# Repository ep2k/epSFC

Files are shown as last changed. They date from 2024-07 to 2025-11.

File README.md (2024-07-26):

# epSFC - SUPER Famicom Emulator on an FPGA

epSFC is an implementation of Nintendo's __SUPER Famicom (SFC)__ written in SystemVerilog.
It works on an FPGA board with a board for connection to SFC cartridges.

The operation has been confirmed with Terasic DE0-CV Board.

<br>

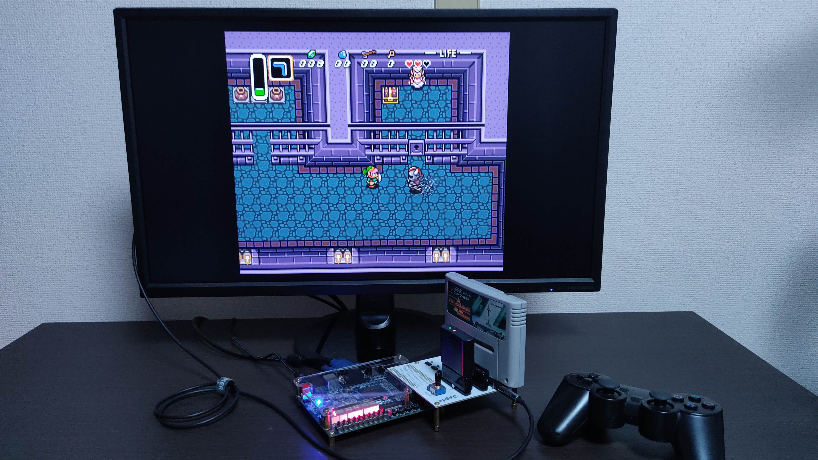
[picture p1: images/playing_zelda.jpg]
Playing The Legend of Zelda: A Link to the Past Playing The Legend of Zelda: A Link to the Past (1991, Nintendo)


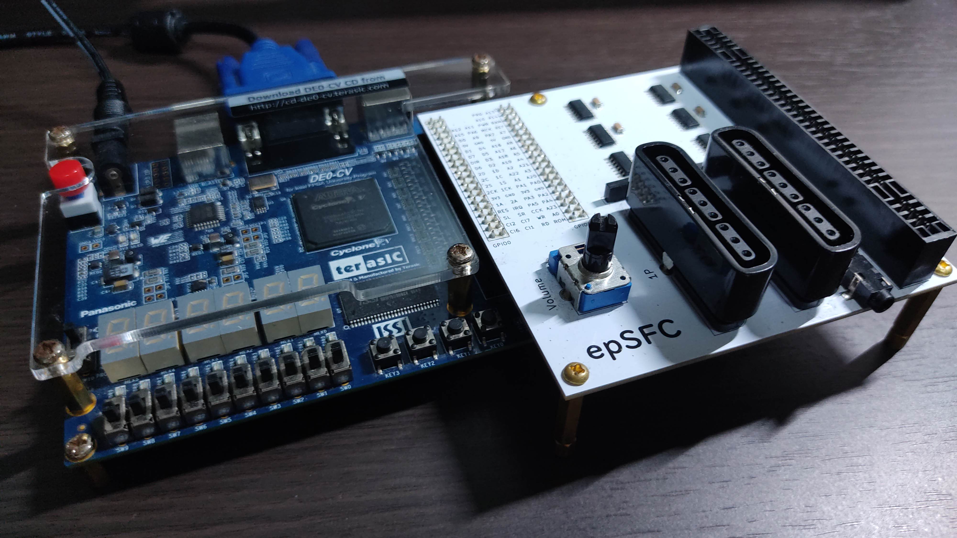
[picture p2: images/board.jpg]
Terasic DE0-CV and my own board for connecting the FPGA and SFC cartridges


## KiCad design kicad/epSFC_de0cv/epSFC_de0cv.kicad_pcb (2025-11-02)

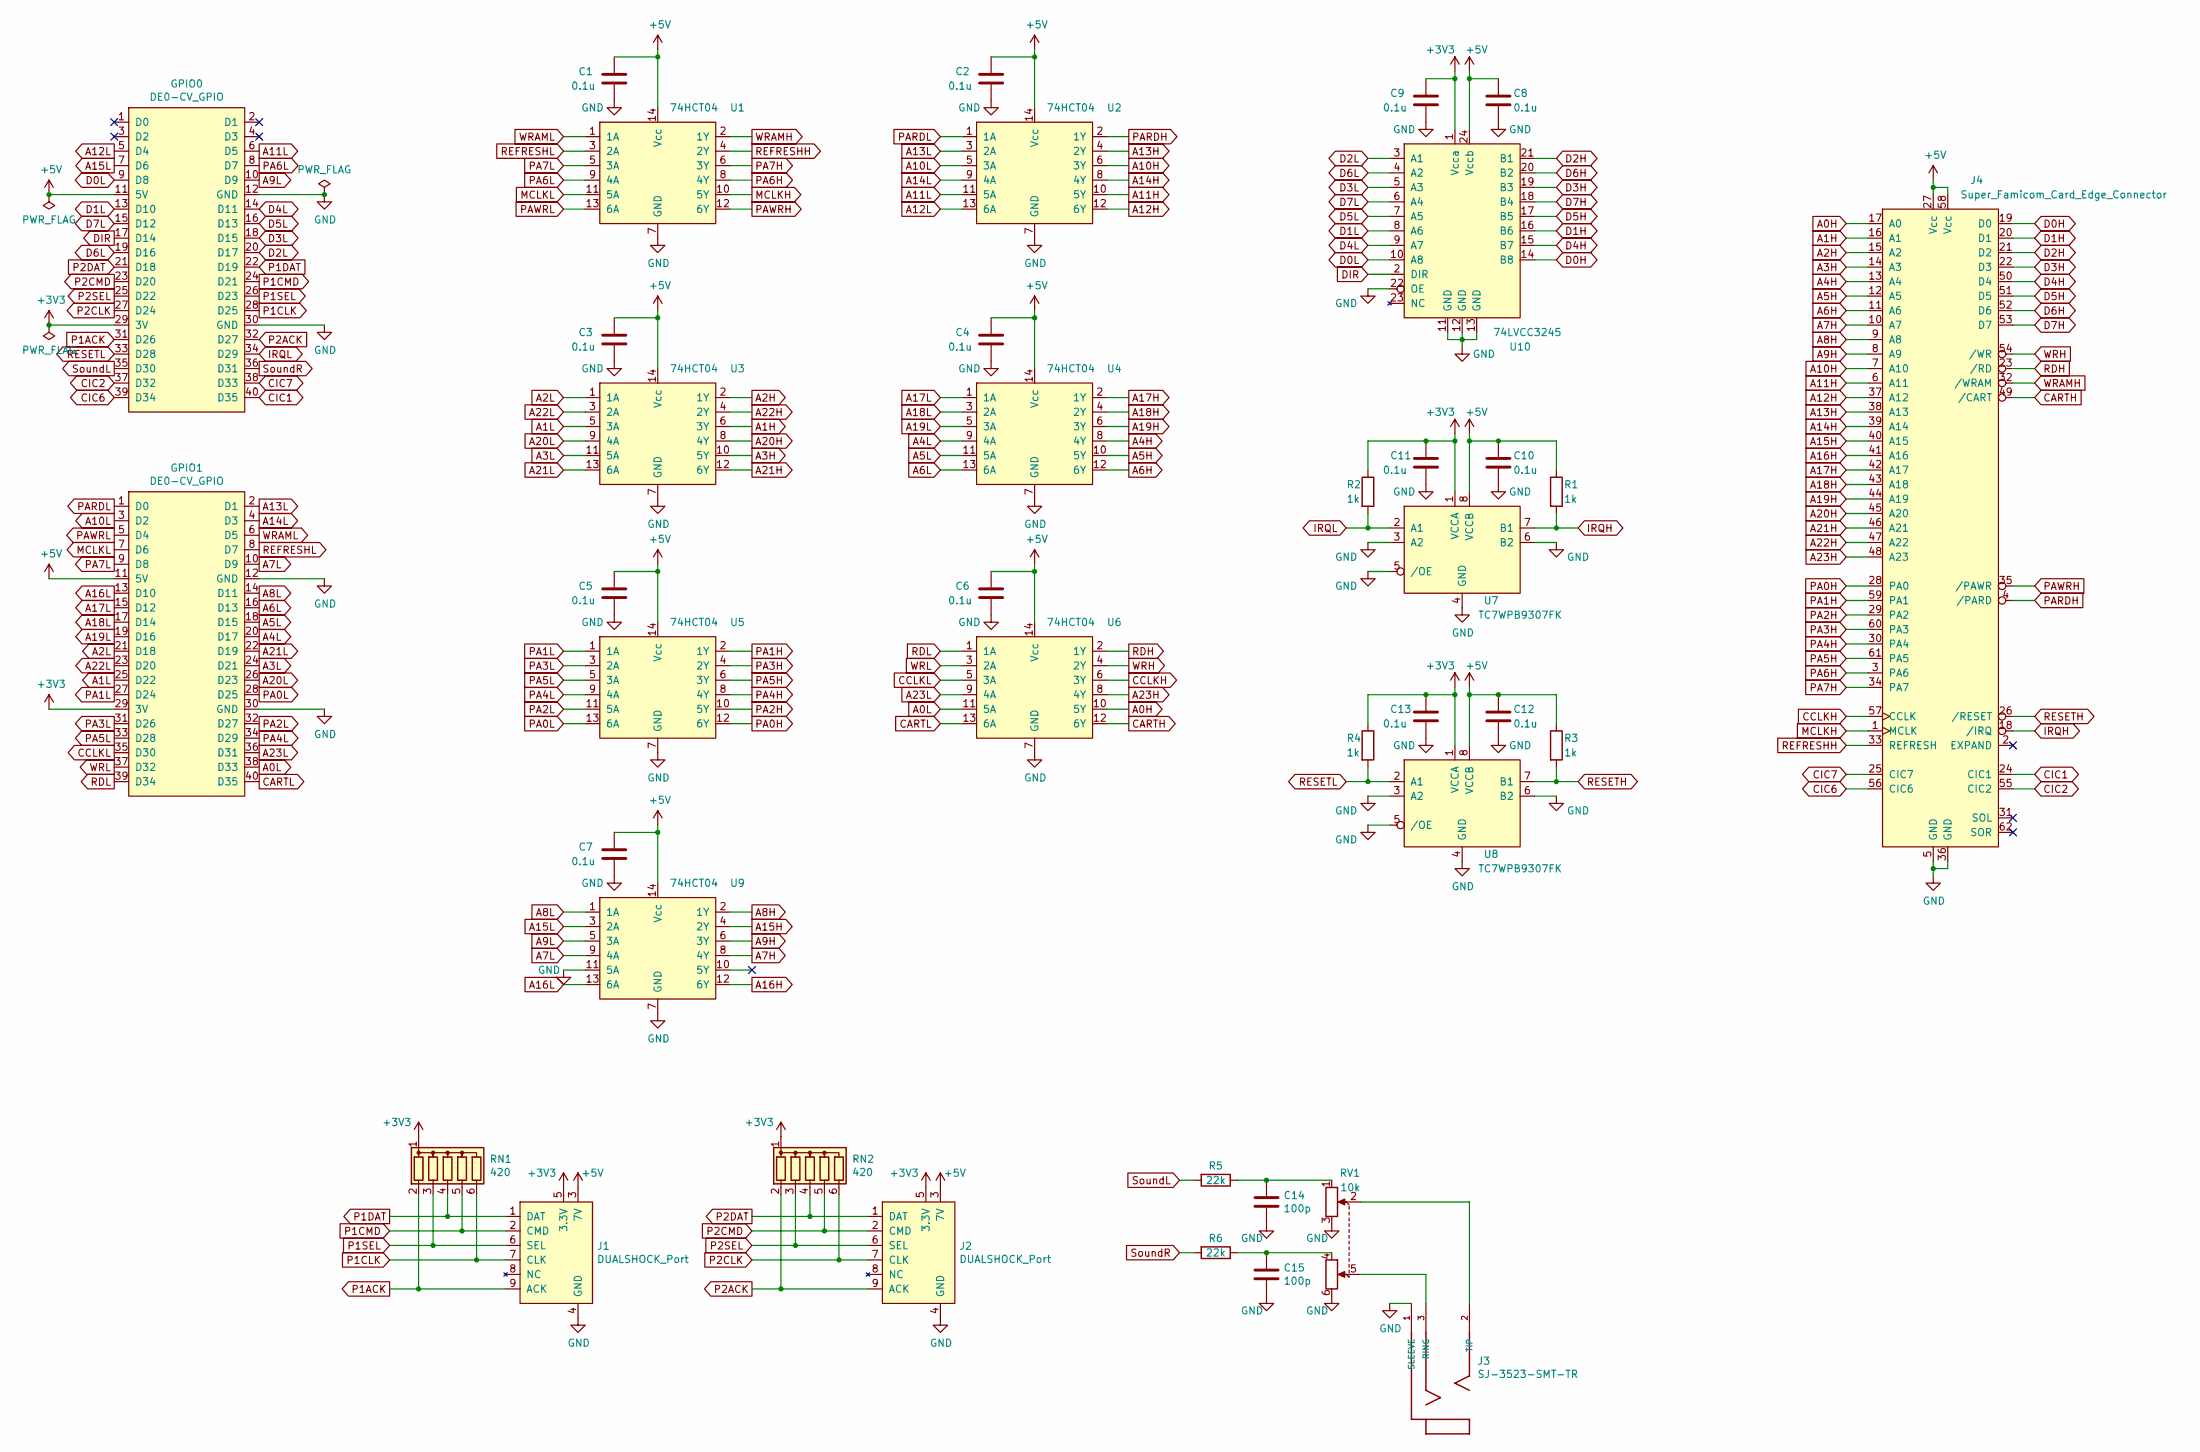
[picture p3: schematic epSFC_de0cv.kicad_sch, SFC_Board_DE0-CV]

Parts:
C1, C2, C3, C4, C5, C6, C7, C8, C9, C10, C11, C12, C13: 0.1u; C_1206_3216Metric_Pad1.33x1.80mm_HandSolder
C14, C15: 100p; C_1206_3216Metric_Pad1.33x1.80mm_HandSolder
GPIO0, GPIO1: DE0-CV_GPIO; PinSocket_2x20_P2.54mm_Vertical_Back
J1, J2: DUALSHOCK_Port
J3: SJ-3523-SMT-TR; CUI_SJ-3523-SMT-TR
J4: Super_Famicom_Card_Edge_Connector; SuperFamicom_Card_Edge_Connector
R1, R2, R3, R4: 1k; R_1206_3216Metric_Pad1.30x1.75mm_HandSolder
R5, R6: 22k; R_1206_3216Metric_Pad1.30x1.75mm_HandSolder
RN1, RN2: 420; R_Array_SIP6
RV1: 10k; Potentiometer_Bourns_PTV112
U1, U2, U3, U4, U5, U6, U9: 74HCT04; SOIC-14_3.9x8.7mm_P1.27mm
U7, U8: TC7WPB9307FK; US8
U10: 74LVCC3245; SO-24_5.3x15mm_P1.27mm

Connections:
+3V3: C9.1, C11.1, C13.1, GPIO0.29 (3V), GPIO1.29 (3V), J1.5 (3.3V), J2.5 (3.3V), R2.1, R4.1, RN1.1 (common), RN2.1 (common), U7.1 (VCCA), U8.1 (VCCA), U10.1 (Vcca)
+5V: C1.1, C2.1, C3.1, C4.1, C5.1, C6.1, C7.1, C8.1, C10.1, C12.1, GPIO0.11 (5V), GPIO1.11 (5V), J1.3 (7V), J2.3 (7V), J4.27 (Vcc), J4.58 (Vcc), R1.1, R3.1, U1.14 (Vcc), U2.14 (Vcc), U3.14 (Vcc), U4.14 (Vcc), U5.14 (Vcc), U6.14 (Vcc), U7.8 (VCCB), U8.8 (VCCB), U9.14 (Vcc), U10.24 (Vccb)
A0H: J4.17 (A0), U6.10 (5Y)
A0L: GPIO1.38 (D33), U6.11 (5A)
A1H: J4.16 (A1), U3.6 (3Y)
A1L: GPIO1.25 (D22), U3.5 (3A)
A2H: J4.15 (A2), U3.2 (1Y)
A2L: GPIO1.21 (D18), U3.1 (1A)
A3H: J4.14 (A3), U3.10 (5Y)
A3L: GPIO1.24 (D21), U3.11 (5A)
A4H: J4.13 (A4), U4.8 (4Y)
A4L: GPIO1.20 (D17), U4.9 (4A)
A5H: J4.12 (A5), U4.10 (5Y)
A5L: GPIO1.18 (D15), U4.11 (5A)
A6H: J4.11 (A6), U4.12 (6Y)
A6L: GPIO1.16 (D13), U4.13 (6A)
A7H: J4.10 (A7), U9.8 (4Y)
A7L: GPIO1.10 (D9), U9.9 (4A)
A8H: J4.9 (A8), U9.2 (1Y)
A8L: GPIO1.14 (D11), U9.1 (1A)
A9H: J4.8 (A9), U9.6 (3Y)
A9L: GPIO0.10 (D9), U9.5 (3A)
A10H: J4.7 (A10), U2.6 (3Y)
A10L: GPIO1.3 (D2), U2.5 (3A)
A11H: J4.6 (A11), U2.10 (5Y)
A11L: GPIO0.6 (D5), U2.11 (5A)
A12H: J4.37 (A12), U2.12 (6Y)
A12L: GPIO0.5 (D4), U2.13 (6A)
A13H: J4.38 (A13), U2.4 (2Y)
A13L: GPIO1.2 (D1), U2.3 (2A)
A14H: J4.39 (A14), U2.8 (4Y)
A14L: GPIO1.4 (D3), U2.9 (4A)
A15H: J4.40 (A15), U9.4 (2Y)
A15L: GPIO0.7 (D6), U9.3 (2A)
A16H: J4.41 (A16), U9.12 (6Y)
A16L: GPIO1.13 (D10), U9.13 (6A)
A17H: J4.42 (A17), U4.2 (1Y)
A17L: GPIO1.15 (D12), U4.1 (1A)
A18H: J4.43 (A18), U4.4 (2Y)
A18L: GPIO1.17 (D14), U4.3 (2A)
A19H: J4.44 (A19), U4.6 (3Y)
A19L: GPIO1.19 (D16), U4.5 (3A)
A20H: J4.45 (A20), U3.8 (4Y)
A20L: GPIO1.26 (D23), U3.9 (4A)
A21H: J4.46 (A21), U3.12 (6Y)
A21L: GPIO1.22 (D19), U3.13 (6A)
A22H: J4.47 (A22), U3.4 (2Y)
A22L: GPIO1.23 (D20), U3.3 (2A)
A23H: J4.48 (A23), U6.8 (4Y)
A23L: GPIO1.36 (D31), U6.9 (4A)
CARTH: J4.49 (/CART), U6.12 (6Y)
CARTL: GPIO1.40 (D35), U6.13 (6A)
CCLKH: J4.57 (CCLK), U6.6 (3Y)
CCLKL: GPIO1.35 (D30), U6.5 (3A)
CIC1: GPIO0.40 (D35), J4.24 (CIC1)
CIC2: GPIO0.37 (D32), J4.55 (CIC2)
CIC6: GPIO0.39 (D34), J4.56 (CIC6)
CIC7: GPIO0.38 (D33), J4.25 (CIC7)
D0H: J4.19 (D0), U10.14 (B8)
D0L: GPIO0.9 (D8), U10.10 (A8)
D1H: J4.20 (D1), U10.16 (B6)
D1L: GPIO0.13 (D10), U10.8 (A6)
D2H: J4.21 (D2), U10.21 (B1)
D2L: GPIO0.20 (D17), U10.3 (A1)
D3H: J4.22 (D3), U10.19 (B3)
D3L: GPIO0.18 (D15), U10.5 (A3)
D4H: J4.50 (D4), U10.15 (B7)
D4L: GPIO0.14 (D11), U10.9 (A7)
D5H: J4.51 (D5), U10.17 (B5)
D5L: GPIO0.16 (D13), U10.7 (A5)
D6H: J4.52 (D6), U10.20 (B2)
D6L: GPIO0.19 (D16), U10.4 (A2)
D7H: J4.53 (D7), U10.18 (B4)
D7L: GPIO0.15 (D12), U10.6 (A4)
DIR: GPIO0.17 (D14), U10.2 (DIR)
GND: C1.2, C2.2, C3.2, C4.2, C5.2, C6.2, C7.2, C8.2, C9.2, C10.2, C11.2, C12.2, C13.2, C14.2, C15.2, GPIO0.12 (GND), GPIO0.30 (GND), GPIO1.12 (GND), GPIO1.30 (GND), J1.4 (GND), J2.4 (GND), J3.1 (SLEEVE), J4.5 (GND), J4.36 (GND), RV1.3, RV1.6, U1.7 (GND), U2.7 (GND), U3.7 (GND), U4.7 (GND), U5.7 (GND), U6.7 (GND), U7.3 (A2), U7.4 (GND), U7.5 (/OE), U7.6 (B2), U8.3 (A2), U8.4 (GND), U8.5 (/OE), U8.6 (B2), U9.7 (GND), U9.11 (5A), U10.11 (GND), U10.12 (GND), U10.13 (GND), U10.22 (OE)
IRQH: J4.18 (/IRQ), R1.2, U7.7 (B1)
IRQL: GPIO0.34 (D29), R2.2, U7.2 (A1)
MCLKH: J4.1 (MCLK), U1.10 (5Y)
MCLKL: GPIO1.7 (D6), U1.11 (5A)
unnamed: C14.1, R5.1, RV1.1
unnamed: C15.1, R6.1, RV1.4
unnamed: J3.3 (RING), RV1.5
unnamed: J3.2 (TIP), RV1.2
P1ACK: GPIO0.31 (D26), J1.9 (ACK), RN1.2 (R1)
P1CLK: GPIO0.28 (D25), J1.7 (CLK), RN1.6 (R5)
P1CMD: GPIO0.24 (D21), J1.2 (CMD), RN1.5 (R4)
P1DAT: GPIO0.22 (D19), J1.1 (DAT), RN1.4 (R3)
P1SEL: GPIO0.26 (D23), J1.6 (SEL), RN1.3 (R2)
P2ACK: GPIO0.32 (D27), J2.9 (ACK), RN2.2 (R1)
P2CLK: GPIO0.27 (D24), J2.7 (CLK), RN2.6 (R5)
P2CMD: GPIO0.23 (D20), J2.2 (CMD), RN2.5 (R4)
P2DAT: GPIO0.21 (D18), J2.1 (DAT), RN2.4 (R3)
P2SEL: GPIO0.25 (D22), J2.6 (SEL), RN2.3 (R2)
PA0H: J4.28 (PA0), U5.12 (6Y)
PA0L: GPIO1.28 (D25), U5.13 (6A)
PA1H: J4.59 (PA1), U5.2 (1Y)
PA1L: GPIO1.27 (D24), U5.1 (1A)
PA2H: J4.29 (PA2), U5.10 (5Y)
PA2L: GPIO1.32 (D27), U5.11 (5A)
PA3H: J4.60 (PA3), U5.4 (2Y)
PA3L: GPIO1.31 (D26), U5.3 (2A)
PA4H: J4.30 (PA4), U5.8 (4Y)
PA4L: GPIO1.34 (D29), U5.9 (4A)
PA5H: J4.61 (PA5), U5.6 (3Y)
PA5L: GPIO1.33 (D28), U5.5 (3A)
PA6H: J4.3 (PA6), U1.8 (4Y)
PA6L: GPIO0.8 (D7), U1.9 (4A)
PA7H: J4.34 (PA7), U1.6 (3Y)
PA7L: GPIO1.9 (D8), U1.5 (3A)
PARDH: J4.4 (/PARD), U2.2 (1Y)
PARDL: GPIO1.1 (D0), U2.1 (1A)
PAWRH: J4.35 (/PAWR), U1.12 (6Y)
PAWRL: GPIO1.5 (D4), U1.13 (6A)
RDH: J4.23 (/RD), U6.2 (1Y)
RDL: GPIO1.39 (D34), U6.1 (1A)
REFRESHH: J4.33 (REFRESH), U1.4 (2Y)
REFRESHL: GPIO1.8 (D7), U1.3 (2A)
RESETH: J4.26 (/RESET), R3.2, U8.7 (B1)
RESETL: GPIO0.33 (D28), R4.2, U8.2 (A1)
SoundL: GPIO0.35 (D30), R5.2
SoundR: GPIO0.36 (D31), R6.2
WRAMH: J4.32 (/WRAM), U1.2 (1Y)
WRAML: GPIO1.6 (D5), U1.1 (1A)
WRH: J4.54 (/WR), U6.4 (2Y)
WRL: GPIO1.37 (D32), U6.3 (2A)

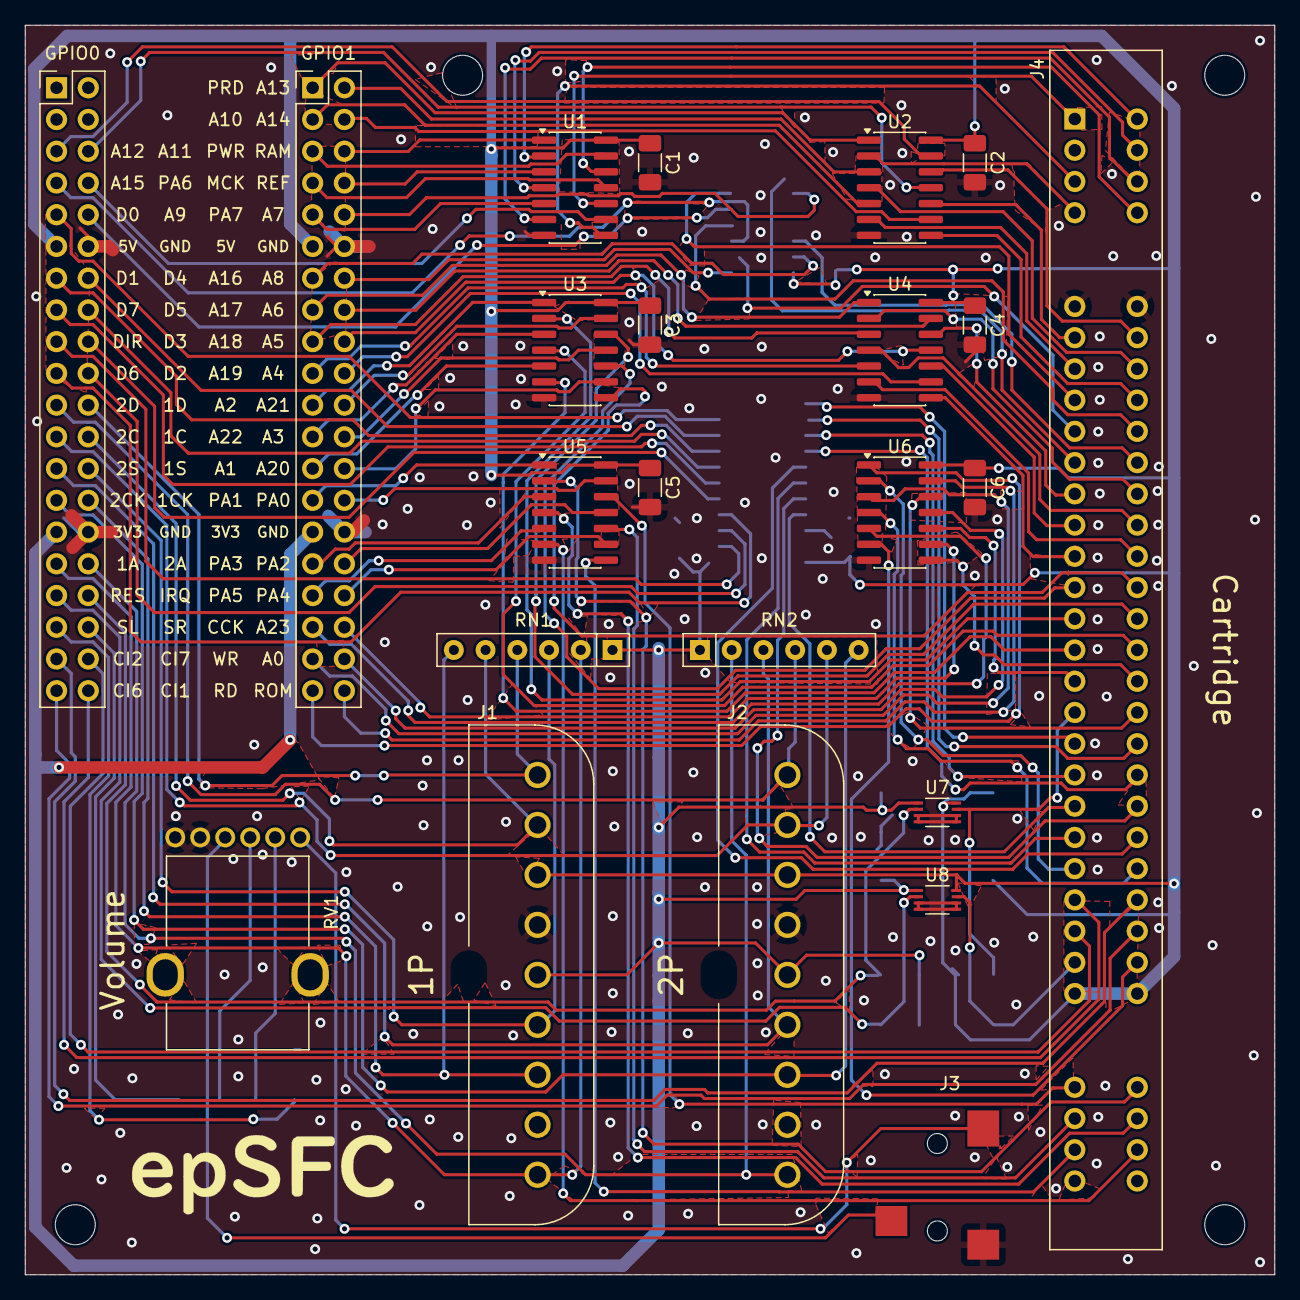
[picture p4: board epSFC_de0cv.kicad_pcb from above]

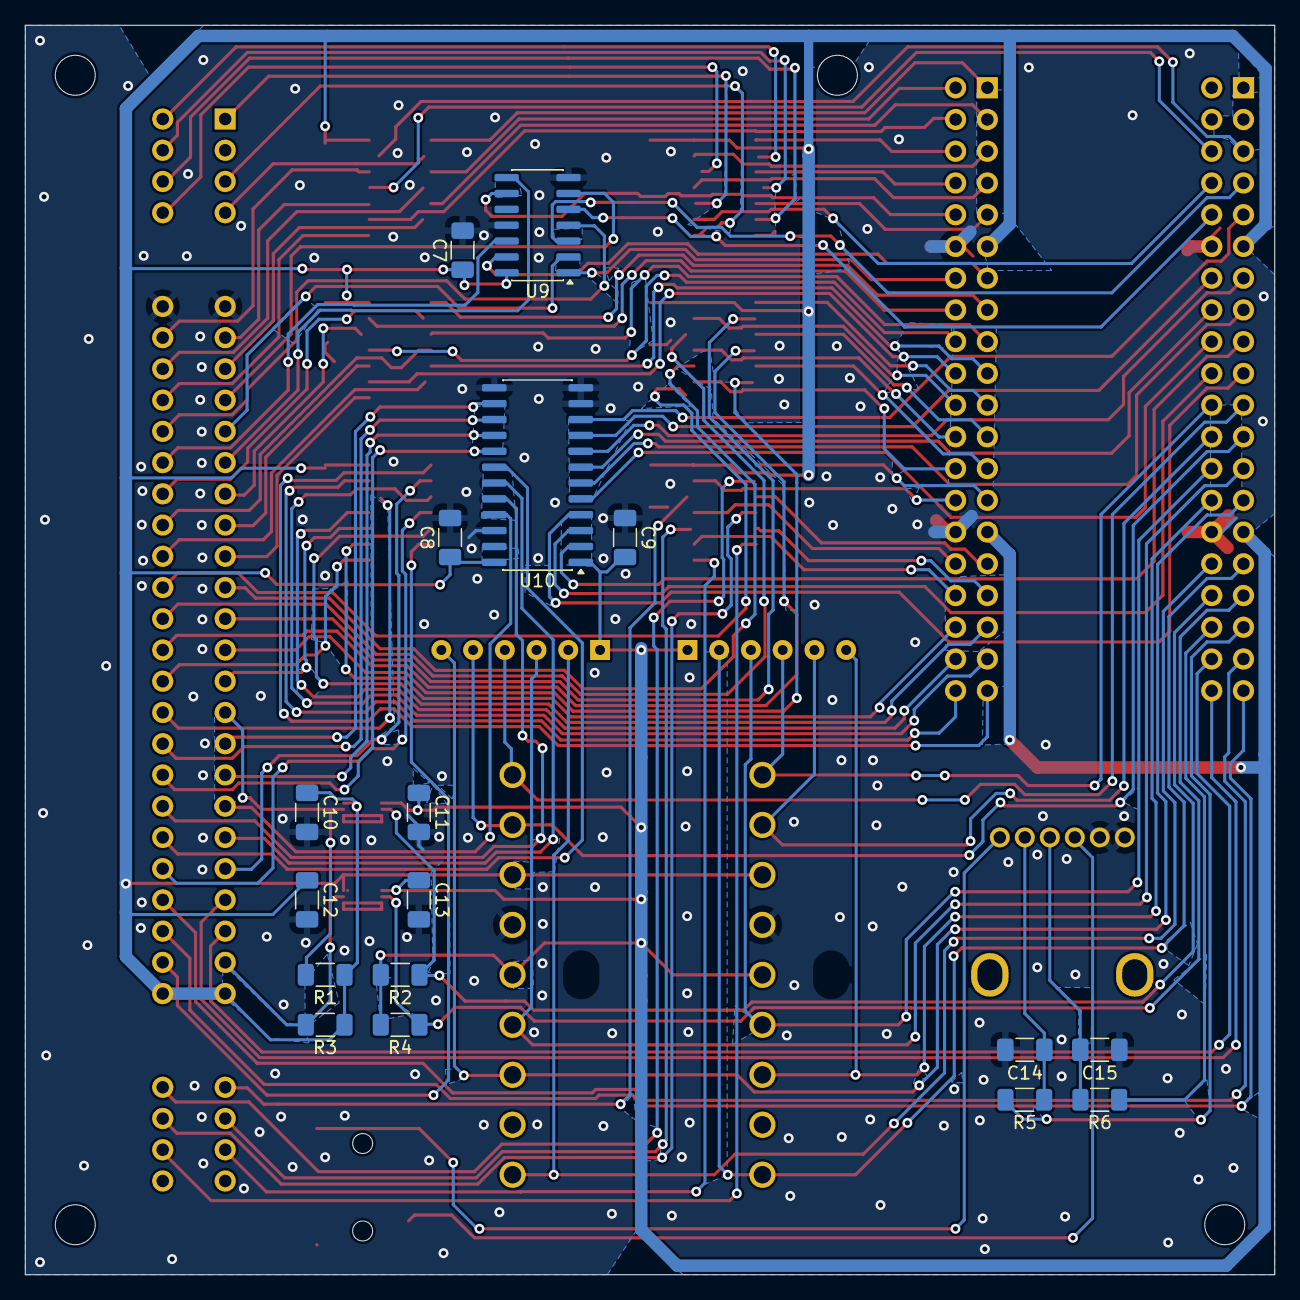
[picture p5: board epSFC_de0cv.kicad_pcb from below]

Board: 2 copper layers, 100.0 x 100.0 mm, 40 parts (17 on the bottom side), 126 nets.

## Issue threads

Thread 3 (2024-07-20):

BG Mode 7の実装

ep2k, 2024-07-20:
PPUの「BG Mode 7」（回転，拡大）を実装する
最低限，mode_7というModuleが存在し，何らかの処理が働いている状態にする

ep2k, 2024-07-28:
- pixel_mixerに入力するbg_pixel[0]をbg7（Mode7モジュール）が出力するpixelに
- EXTBGの実装
  - pixel_mixerに入力するbg_pixel[1]をpixel.main=bg_pixel[0].main[6:0], pixel.prior=bg_pixel[0].main[7]
  - refer_pal_typeにBG2の7bppのものを追加
- Mode 7用 Direct Colorの実装
  - pixel_mixer内のdirect_color信号をbgmodeで場合分け

Closed 2024-07-30.

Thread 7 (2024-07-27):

DMA時のカートリッジとのデータ方向信号（cart_send）が不完全

ep2k, 2024-07-27:
rtl/console.svにて
```
assign cart_send = dma ? (~(cart_en & dma_a2b)) : (a_write | b_write);
```
としているが，例えば dma=1, dma_a2b=1 (A→B) , a_addr = 3000h (拡張ポートのためカートリッジにアクセスするがcart_en=0) のときにcart_send=1となってしまう．

Closed 2024-07-27.

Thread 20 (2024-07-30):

Direct Colorでcolor=0のときに透明にする処理を行っていない

ep2k, 2024-07-30:
pixel_mixer.svにて
```systemverilog
end else if ((refer_pal_main == BG1_8) & use_direct_color) begin
    color_main <= direct_color;
end else begin
```
としており，color=0のときに透明にする（BG1が無視されて下のレイヤーが表示される）処理を行っていない

ep2k, 2024-07-30:
direct_color = 0 の時点でbg_pixel[0]=0であり，refer_pal_main != BG1_8 となるため，今のままで自然に透明処理となる．
逆に，direct_color ≒ 0 かつ refer_pal_main != BG1_8 （bg_pixel[0].palette ≠ 0）で問題となる．

Closed 2024-07-30.

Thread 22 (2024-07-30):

Direct Color で color != 0 かつ pixel=0 のときに Direct Color が適用されない

ep2k, 2024-07-30:
pixel_mixer.svにて
```systemverilog
end else if ((refer_pal_main == BG1_8) & use_direct_color) begin
    color_main <= direct_color;
end else begin
```
としており，direct_color ≒ 0 かつ refer_pal_main != BG1_8 （bg_pixel[0].palette ≠ 0）のときに direct_color が適用されない

Closed 2024-07-31.

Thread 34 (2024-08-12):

SPC700「MOV dp, dp」「MOV dp, #imm」の修正

ep2k, 2024-08-12:
- 「MOV dp, dp」が5サイクルのはずが6サイクルに
  - temp ← temp + 0（他の命令ではtemp + mem_rdataの演算を行ってtempに格納するために使用）のサイクルが不必要
- 「MOV dp, dp」，「MOV dp, #imm」がどちらもPSWを変更しないはずが変更している
  - s_state_decoder.svの (state == SS_CALC_TEMP_MEMDR) | (state == SS_CALC_TEMP_MEMDP) を修正

Closed 2024-08-12.

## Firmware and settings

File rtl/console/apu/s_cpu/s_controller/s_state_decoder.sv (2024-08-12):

// ========================================
//  State Decoder in SPC700 CPU Controller
// ========================================

// Copyright(C) 2024 ep2k All Rights Reserved.

module s_state_decoder
    import s_cpu_pkg::*;
(
    input state_type state,
    input instruction_type instruction,

    output ctl_signals_type ctl_signals
);

    instruction_type i;
    ctl_signals_type s;

    assign i = instruction;
    assign ctl_signals = s;

    always_comb begin

        s.mem_addr_src = SC_MA_PC;
        s.mem_read = 1'b0;
        s.mem_write = 1'b0;

        s.wdata_src = SC_W_ALUY;
        s.reg1_write = 1'b0;
        s.reg2_write = 1'b0;
        s.op_write = 1'b0;
        s.temp_write = 1'b0;

        s.psw_wdata_src = SC_PW_ALUF;
        s.psw_write = 8'h0;

        s.pc_wdata_src = SC_PCW_PC_1;
        s.pc_write = 2'b00;

        s.addr_wdata_src = SC_AW_ALUY;
        s.addr_write = 2'b00;

        s.alu_a_src = SC_AA_REG1;
        s.alu_b_src = SC_AB_0;
        s.alu_c_src = SC_AC_C;
        s.alu_control = SC_ACTL_ADD;
        s.alu_bit8 = 1'b0;
        s.c2_write = 1'b0;

        s.bitalu_b_src = SC_BAB_OP75;
        s.bitalu_control = SC_BACTL_AND1_C;

        s.daas_control = SC_DACTL_DAA;

        s.mul_init = 1'b0;
        s.mul = 1'b0;
        s.div_init = 1'b0;
        s.div = 1'b0;
        s.div_last = 1'b0;

        if ((state == SS_OPFETCH) | (state == SS_ADLFETCH) | (state == SS_ADHFETCH) | (state == SS_TEMPFETCH)) begin
            
            // op/addr[7:0]/addr[15:8]/temp <- mem[PC++]

            s.mem_addr_src = SC_MA_PC;
            s.mem_read = 1'b1;

            s.addr_wdata_src = SC_AW_RD;
            s.wdata_src = SC_W_RD;

            s.op_write = (state == SS_OPFETCH);
            s.addr_write[0] = (state == SS_ADLFETCH);
            s.addr_write[1] = (state == SS_ADHFETCH);
            s.temp_write = (state == SS_TEMPFETCH);
            
            // s.alu_a_src = SC_AA_PC;
            // s.alu_b_src = SC_AB_1;
            // s.alu_control = SC_ACTL_ADD;
            // s.alu_bit8 = 1'b0;
            // s.pc_wdata_src = SC_PCW_ALUY;
            s.pc_wdata_src = SC_PCW_PC_1;
            s.pc_write = 2'b11;

        end else if (state == SS_READ_MEMDP) begin
            
            // mem[dp]

            s.mem_addr_src = SC_MA_DP;
            s.mem_read = 1'b1;

        end else if ((state == SS_COPY_REG1_REG2) | (state == SS_COPY_REG1_MEMSR)) begin
            
            // reg1 <- reg2/mem[01, reg2]

            s.mem_addr_src = SC_MA_SR2;
            s.mem_read = (state == SS_COPY_REG1_MEMSR);

            s.alu_a_src = (state == SS_COPY_REG1_REG2) ? SC_AA_REG2 : SC_AA_RD;
            s.alu_b_src = SC_AB_0;
            s.alu_control = SC_ACTL_ADD;
            s.alu_bit8 = 1'b1;

            s.wdata_src = SC_W_ALUY;
            s.reg1_write = 1'b1;

            s.psw_wdata_src = SC_PW_ALUF;
            {s.psw_write[N], s.psw_write[Z]} = (i == SI_MOV) ? 2'b11 : 2'b00;

        end else if ((state == SS_COPY_MEMDR_TEMP) | (state == SS_COPY_MEMDP_TEMP) | (state == SS_COPY_MEMDP1_TEMP) | (state == SS_COPY_MEMABS_TEMP) | (state == SS_COPY_MEMABSMINI_TEMP)) begin
            
            // mem[reg2]/mem[dp]/mem[dp+1]/mem[abs]/mem[abs mini] <- temp

            case (state)
                SS_COPY_MEMDR_TEMP: s.mem_addr_src = SC_MA_DR2;
                SS_COPY_MEMDP_TEMP: s.mem_addr_src = SC_MA_DP;
                SS_COPY_MEMDP1_TEMP: s.mem_addr_src = SC_MA_DP_1;
                SS_COPY_MEMABS_TEMP: s.mem_addr_src = SC_MA_ABS;
                SS_COPY_MEMABSMINI_TEMP: s.mem_addr_src = SC_MA_ABSMINI;
                default: ;
            endcase

            s.alu_a_src = SC_AA_TEMP;
            s.alu_b_src = SC_AB_0;
            s.alu_control = SC_ACTL_ADD;
            s.alu_bit8 = 1'b1;
            s.wdata_src = SC_W_ALUY;
            s.mem_write = 1'b1;

        end else if ((state == SS_COPY_MEMDP_REG1) | (state == SS_COPY_MEMSR_REG1)) begin
            
            // mem[dp]/mem[01, reg2] <- reg1

            s.mem_addr_src = (state == SS_COPY_MEMDP_REG1) ? SC_MA_DP : SC_MA_SR2;
            s.alu_a_src = SC_AA_REG1;
            s.alu_b_src = SC_AB_0;
            s.alu_control = SC_ACTL_ADD;
            s.alu_bit8 = 1'b1;
            s.wdata_src = SC_W_ALUY;
            s.mem_write = 1'b1;

        end else if (state == SS_COPY_MEMDP1_REG2) begin
            
            // mem[dp+1] <- reg2

            s.mem_addr_src = SC_MA_DP_1;
            s.alu_a_src = SC_AA_REG2;
            s.alu_b_src = SC_AB_0;
            s.alu_control = SC_ACTL_ADD;
            s.alu_bit8 = 1'b1;
            s.wdata_src = SC_W_ALUY;
            s.mem_write = 1'b1;

        end else if ((state == SS_COPY_MEMSRP2_PCH) | (state == SS_COPY_MEMSRP1_PCL) | (state == SS_COPY_MEMSR_PSW)) begin
            
            // mem[01, reg2+2] <- pc[15:8]
            // mem[01, reg2+1] <- pc[7:0]
            // mem[01, reg2] <- psw

            case (state)
                SS_COPY_MEMSRP2_PCH: {s.mem_addr_src, s.wdata_src} = {SC_MA_SR2_2, SC_W_PCH};
                SS_COPY_MEMSRP1_PCL: {s.mem_addr_src, s.wdata_src} = {SC_MA_SR2_1, SC_W_PCL};
                SS_COPY_MEMSR_PSW: {s.mem_addr_src, s.wdata_src} = {SC_MA_SR2, SC_W_PSW};
                default: ;
            endcase

            s.mem_write = 1'b1;

        end else if ((state == SS_COPY_ADL_MEMDT) | (state == SS_COPY_ADL_MEMFFDE)) begin

            // addr[7:0] <- mem[temp]/mem[FFDE-{op[7:4],1'b0}]

            s.mem_addr_src = (state == SS_COPY_ADL_MEMDT)
                        ? SC_MA_DT : SC_MA_FFDE;
            s.mem_read = 1'b1;

            s.addr_wdata_src = SC_AW_RD;
            s.addr_write[0] = 1'b1;
            
        end else if ((state == SS_COPY_ADH_MEMDT1) | (state == SS_COPY_ADH_MEMFFDF)) begin

            // addr[15:8] <- mem[temp+1]/mem[FFDF-{op[7:4], 1'b0}]

            s.mem_addr_src = (state == SS_COPY_ADH_MEMDT1)
                        ? SC_MA_DT_1 : SC_MA_FFDF;
            s.mem_read = 1'b1;

            s.addr_wdata_src = SC_AW_RD;
            s.addr_write[1] = 1'b1;
            
        end else if ((state == SS_COPY_PCL_MEMSRP1) | (state == SS_COPY_PCL_MEMFFDE)) begin
            
            // pc[7:0] <- mem[01, reg2+1]/mem[FFDE-{op[7:4], 1'b0}]

            s.mem_addr_src = (state == SS_COPY_PCL_MEMSRP1)
                        ? SC_MA_SR2_1 : SC_MA_FFDE;
            s.mem_read = 1'b1;

            s.pc_wdata_src = SC_PCW_RD;
            s.pc_write[0] = 1'b1;

        end else if ((state == SS_COPY_PCH_MEMSRP2) | (state == SS_COPY_PCH_MEMFFDF)) begin
            
            // pc[15:8] <- mem[01, reg2+2]/mem[FFDF-{op[7:4], 1'b0}]

            s.mem_addr_src = (state == SS_COPY_PCH_MEMSRP2)
                        ? SC_MA_SR2_2 : SC_MA_FFDF;
            s.mem_read = 1'b1;

            s.pc_wdata_src = SC_PCW_RD;
            s.pc_write[1] = 1'b1;
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

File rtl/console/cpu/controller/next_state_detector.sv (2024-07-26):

// ==================================================
//  Next State Detector in 65186 CPU Controller
// ==================================================

// Copyright(C) 2024 ep2k All Rights Reserved.

module next_state_detector
    import cpu_pkg::*;
(
    input state_type state,
    input addressing_type addressing,

    input logic e,
    input logic carry,
    input logic m8,
    input logic x8,
    input logic i_mem,
    input logic dplz,

    output state_type next_state
);

    always_comb begin

        if ((addressing == A_SOFT_INT) | (addressing == A_HARD_INT)) begin
            
            case (state)
                // S_FETCH_OPCODE: next_state = (addressing == A_HARD_INT) ? S_PC_DEC : S_PC_INC;
                S_PC_DEC: next_state = e ? S_PUSH_H : S_PUSH_B;
                S_PC_INC: next_state = e ? S_PUSH_H : S_PUSH_B;
                S_PUSH_B: next_state = S_PUSH_H;
                S_PUSH_H: next_state = S_PUSH_L;
                S_PUSH_L: next_state = S_PUSH_P;
                S_PUSH_P: next_state = S_OP_CALC;
                default: next_state = S_ERROR;
            endcase

        end else if (addressing == A_WAIT) begin

            next_state = S_FETCH_OPCODE;

        end else if ((addressing == A_ABS) | (addressing == A_ABS_JMP) | (addressing == A_ABSL_JMP)) begin
            
            case (state)
                // S_FETCH_OPCODE: next_state = S_FETCH_OPRAND_L;
                S_FETCH_OPRAND_L: next_state = S_FETCH_OPRAND_H;
                S_FETCH_OPRAND_H: next_state = S_OP_CALC;
                default: next_state = S_ERROR;
            endcase

        end else if ((addressing == A_ABSX) | (addressing == A_ABSY) | (addressing == A_ABSX_JMP)) begin
            
            case (state)
                // S_FETCH_OPCODE: next_state = S_FETCH_OPRAND_L;
                S_FETCH_OPRAND_L: next_state = S_FETCH_OPRAND_H;
                S_FETCH_OPRAND_H: begin
                        if ((~x8) | carry | i_mem | (addressing == A_ABSX_JMP)) begin
                            // next_state = (addressing == A_ABSY) ? S_ADD_ADDRH_YH : S_ADD_ADDRH_XH; // A_ABS_JMPも?
                            next_state = S_ADD_ADDRB_CARRY;
                        end else begin
                            next_state = S_OP_CALC;
                        end
                    end
                S_ADD_ADDRB_CARRY: next_state = S_OP_CALC;
                default: next_state = S_ERROR;
            endcase

        end else if ((addressing == A_ABSL) | (addressing == A_ABSLX)) begin
            
            case (state)
                // S_FETCH_OPCODE: next_state = S_FETCH_OPRAND_L;
                S_FETCH_OPRAND_L: next_state = S_FETCH_OPRAND_H;
                S_FETCH_OPRAND_H: next_state = S_FETCH_OPRAND_B;
                S_FETCH_OPRAND_B: next_state = S_OP_CALC;
                default: next_state = S_ERROR;
            endcase

        end else if (addressing == A_DP) begin
            
            case (state)
                // S_FETCH_OPCODE: next_state = S_FETCH_OPRAND_L;
                S_FETCH_OPRAND_L: next_state = dplz ? S_OP_CALC : S_ADD_ADDR_DPL;
                S_ADD_ADDR_DPL: next_state = S_OP_CALC;
                default: next_state = S_ERROR;
            endcase

        end else if (addressing == A_DPX) begin
            
            case (state)
                // S_FETCH_OPCODE: next_state = S_FETCH_OPRAND_L;
                S_FETCH_OPRAND_L: next_state = dplz ? S_ADD_ADDR_X : S_ADD_ADDR_DPL;
                S_ADD_ADDR_DPL: next_state = S_ADD_ADDR_X;
                S_ADD_ADDR_X: next_state = S_OP_CALC;
                default: next_state = S_ERROR;
            endcase

        end else if (addressing == A_DPY) begin
            
            case (state)
                // S_FETCH_OPCODE: next_state = S_FETCH_OPRAND_L;
                S_FETCH_OPRAND_L: next_state = dplz ? S_ADD_ADDR_Y : S_ADD_ADDR_DPL;
                S_ADD_ADDR_DPL: next_state = S_ADD_ADDR_Y;
                S_ADD_ADDR_Y: next_state = S_OP_CALC;
                default: next_state = S_ERROR;
            endcase

        end else if (addressing == A_INDP) begin
            
            case (state)
                // S_FETCH_OPCODE: next_state = S_FETCH_OPRAND_L;
                S_FETCH_OPRAND_L: next_state = dplz ? S_READ_ADDR2_L : S_ADD_ADDR2_DPL;
                S_ADD_ADDR2_DPL: next_state = S_READ_ADDR2_L;
                S_READ_ADDR2_L: next_state = S_READ_ADDR2_H;
                S_READ_ADDR2_H: next_state = S_OP_CALC;
                default: next_state = S_ERROR;
            endcase

        end else if (addressing == A_INDPX) begin
            
            case (state)
                // S_FETCH_OPCODE: next_state = S_FETCH_OPRAND_L;
                S_FETCH_OPRAND_L: next_state = dplz ? S_ADD_ADDR2_X : S_ADD_ADDR2_DPL;
                S_ADD_ADDR2_DPL: next_state = S_ADD_ADDR2_X;
                S_ADD_ADDR2_X: next_state = S_READ_ADDR2_L;
                S_READ_ADDR2_L: next_state = S_READ_ADDR2_H;
                S_READ_ADDR2_H: next_state = S_OP_CALC;
                default: next_state = S_ERROR;
            endcase

        end else if (addressing == A_INDPY) begin

            case (state)
                // S_FETCH_OPCODE: next_state = S_FETCH_OPRAND_L;
                S_FETCH_OPRAND_L: next_state = dplz ? S_READ_ADDR2_L : S_ADD_ADDR2_DPL;
                S_ADD_ADDR2_DPL: next_state = S_READ_ADDR2_L;
                S_READ_ADDR2_L: next_state = S_READ_ADDR2_H;
                S_READ_ADDR2_H: next_state = ((~x8) | carry | i_mem) ? S_ADD_ADDRB_CARRY : S_OP_CALC;
                S_ADD_ADDRB_CARRY: next_state = S_OP_CALC;
                default: next_state = S_ERROR;
            endcase
            
        end else if ((addressing == A_INDPL) | (addressing == A_INDPLY)) begin
            
            case (state)
                // S_FETCH_OPCODE: next_state = S_FETCH_OPRAND_L;
                S_FETCH_OPRAND_L: next_state = dplz ? S_READ_ADDR2_L : S_ADD_ADDR2_DPL;
                S_ADD_ADDR2_DPL: next_state = S_READ_ADDR2_L;
                S_READ_ADDR2_L: next_state = S_READ_ADDR2_H;
                S_READ_ADDR2_H: next_state = S_READ_ADDR2_B;
                S_READ_ADDR2_B: next_state = S_OP_CALC;
                default: next_state = S_ERROR;
            endcase

        end else if (addressing == A_SPR) begin
            
            case (state)
                // S_FETCH_OPCODE: next_state = S_FETCH_OPRAND_L;
                S_FETCH_OPRAND_L: next_state = S_ADD_ADDR_SP;
                S_ADD_ADDR_SP: next_state = S_OP_CALC;
                default: next_state = S_ERROR;
            endcase
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

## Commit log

2024-07-26 feat: #2 CPUの追加
2024-07-26 feat: #2 PPUの追加
2024-07-26 feat: #2 APUの追加
2024-07-26 feat: #2 DMA Controllerの追加
2024-07-26 feat: #2 アドレスデコーダの追加
2024-07-26 feat: #2 WRAMの追加
2024-07-26 feat: #2 H/V Interrupt Controller の追加
2024-07-26 feat: #2 乗除算器の追加
2024-07-26 feat: #2 Memory Access Speed Counter の追加
2024-07-26 feat: #2 Joypadの追加
2024-07-26 feat: #2 Refresh信号コントローラーの追加
2024-07-26 feat: #2 Packageファイルの追加
2024-07-26 feat: #2 Console (SFC本体トップモジュール) の追加
2024-07-26 feat: #2 外部制御モジュールの追加
2024-07-26 feat: #2 Clock Generator の追加
2024-07-26 feat: #2 内部カートリッジの追加
2024-07-26 feat: #2 DE0-CV用トップモジュールの追加
2024-07-26 feat: #2 includeファイルテンプレートの追加
2024-07-26 feat: #2 ROMファイルの追加
2024-07-26 feat: #2 DE0-CV用制約ファイルの追加
2024-07-26 chore: #2 .gitignoreの追加
2024-07-26 style: #2 コメントの修正
2024-07-26 docs: #1 READMEの追加
2024-07-27 fix: #7 cart_send信号を修正
2024-07-27 fix: #16 cart_reset_in, cart_irq_in をGPIO入力から反転
2024-07-27 feat: #16 consoleにcart_irq_inを入力
2024-07-29 feat: #3 ppuにbg7モジュール（空）を追加
2024-07-29 feat: #3 bg7に入力するx (x_bg7)を実装
2024-07-29 feat: #3 VRAMアドレスとしてbg7が出力したものを使用する期間を示す信号(bg7_period)を実装
2024-07-29 feat: #3 VRAMに入力するアドレスをL, Hで別の信号にする
2024-07-29 feat: #3 bgmode=7かつbg7_periodのときのVRAMアドレスをbg7が出力するものに変更
2024-07-29 feat: #3 Mode7の乗算を実装（乗算器*2，dot_ctrで乗算内容を変える）
2024-07-29 feat: #3 Mode7の乗算結果を一時保存するレジスタを作成
2024-07-29 feat: #3 bg7のVRAM.X, VRAM.Y計算を実装（dot_enでレジスタに保存）
2024-07-29 feat: #3 VRAMからのタイル番号，8bppピクセルの取得を実装
2024-07-30 feat: #3 Mode7ピクセル出力を実装
2024-07-30 feat: #3 Mode7でbg_pixelをbg7が出力したものとなるように変更
2024-07-30 feat: #3 Mode7をモザイクに対応
2024-07-30 feat: #3 pixel_mixerをMode7に対応
2024-07-30 fix: #3 スプライトのタイルフェッチタイミングに間に合わせるためにBG Mode 7を+7クロック早く動作させる（出力までシフトレジスタで結果を保持）
2024-07-31 fix: #22 refer_pal_selectorでdirect_colorを考慮するように修正
2024-08-02 fix: #14 BG 16x16pxタイルモードでのVRAMタイルデータアドレスを修正
2024-08-03 refactor: #23 モザイク信号をBG Mode 0-6と7で統一
2024-08-03 fix: #10 True H-RESでのVRAMタイルマップアドレス，タイルデータアドレスを修正
2024-08-03 fix: #10 True H-RESでのサブピクセルの処理を修正
2024-08-03 fix: #10 color_right/color_leftの選択にdot_ctr[1]ではなくh_ctr[1]を使用していた問題を修正
2024-08-04 fix: #15 ObjがVRAMアクセス中のCPUからのVRAM書き込みを無効化
2024-08-11 feat: #32 config.vhにCPUサイクル数テストの設定を追加
2024-08-12 feat: #32 65816 CPU に命令サイクル数テスト回路を追加
2024-08-12 feat: #32 SPC700 CPU に命令サイクル数テスト回路を追加
2024-08-12 fix: #34 MOV dp, dp にサイクル数が1多い問題を修正
    [s_next_state_detector.sv]
2024-08-12 fix: #34 「MOV dp, dp」「MOV dp, #imm」でPSWを更新しないように修正
    [s_state_decoder.sv]
2025-11-02 feat: #37 .gitignoreにKiCad関連ファイルを追記
2025-11-02 feat: #37 カートリッジ接続基板のKiCadデータを追加
    [epSFC_de0cv.kicad_pcb, epSFC_de0cv.kicad_sch]
